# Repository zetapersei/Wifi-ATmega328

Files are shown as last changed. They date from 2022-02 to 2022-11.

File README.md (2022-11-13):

# Wifi-ATmega328
### Simple board with esp8266 + ATMega328

##### The board hardware include one esp8266, one AtMega328P together power unit 12-5 vcc -> 3.3V.
##### A Kicad project are available in the hardware folder.
##### Atmega 328 will be programmed by ICSP connector.
#### Software:
> ##### can be used the AT firmware  (loaded in the esp8266) and the [WiFiEspAT library](https://github.com/jandrassy/WiFiEspAT.git)
> ##### try to use with the [WiFiESPNow library](https://github.com/yoursunny/WifiEspNow) running in the esp8266 and manage with the ATMega328
#### Board Top view: 
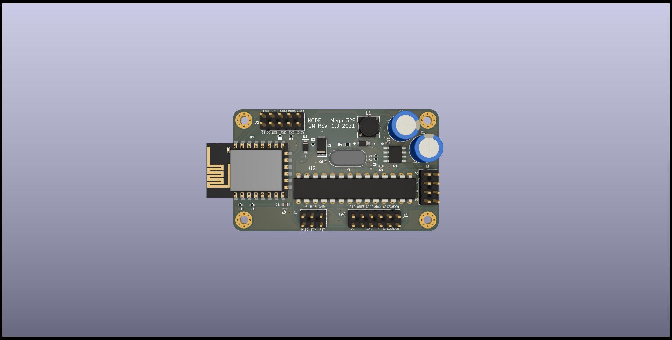
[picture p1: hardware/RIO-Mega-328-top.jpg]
top board


#### Board iso view:
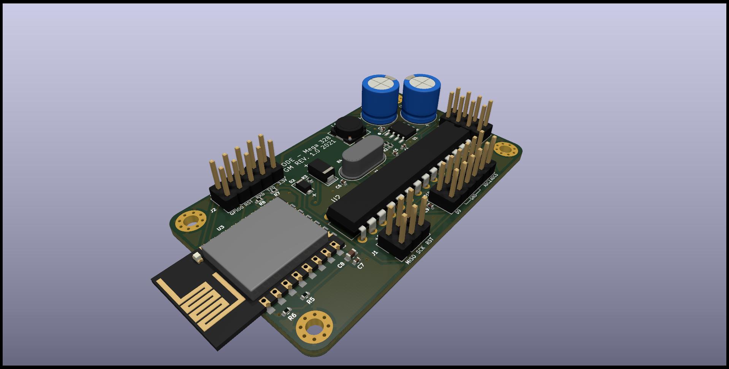
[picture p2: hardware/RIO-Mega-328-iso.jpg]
iso board


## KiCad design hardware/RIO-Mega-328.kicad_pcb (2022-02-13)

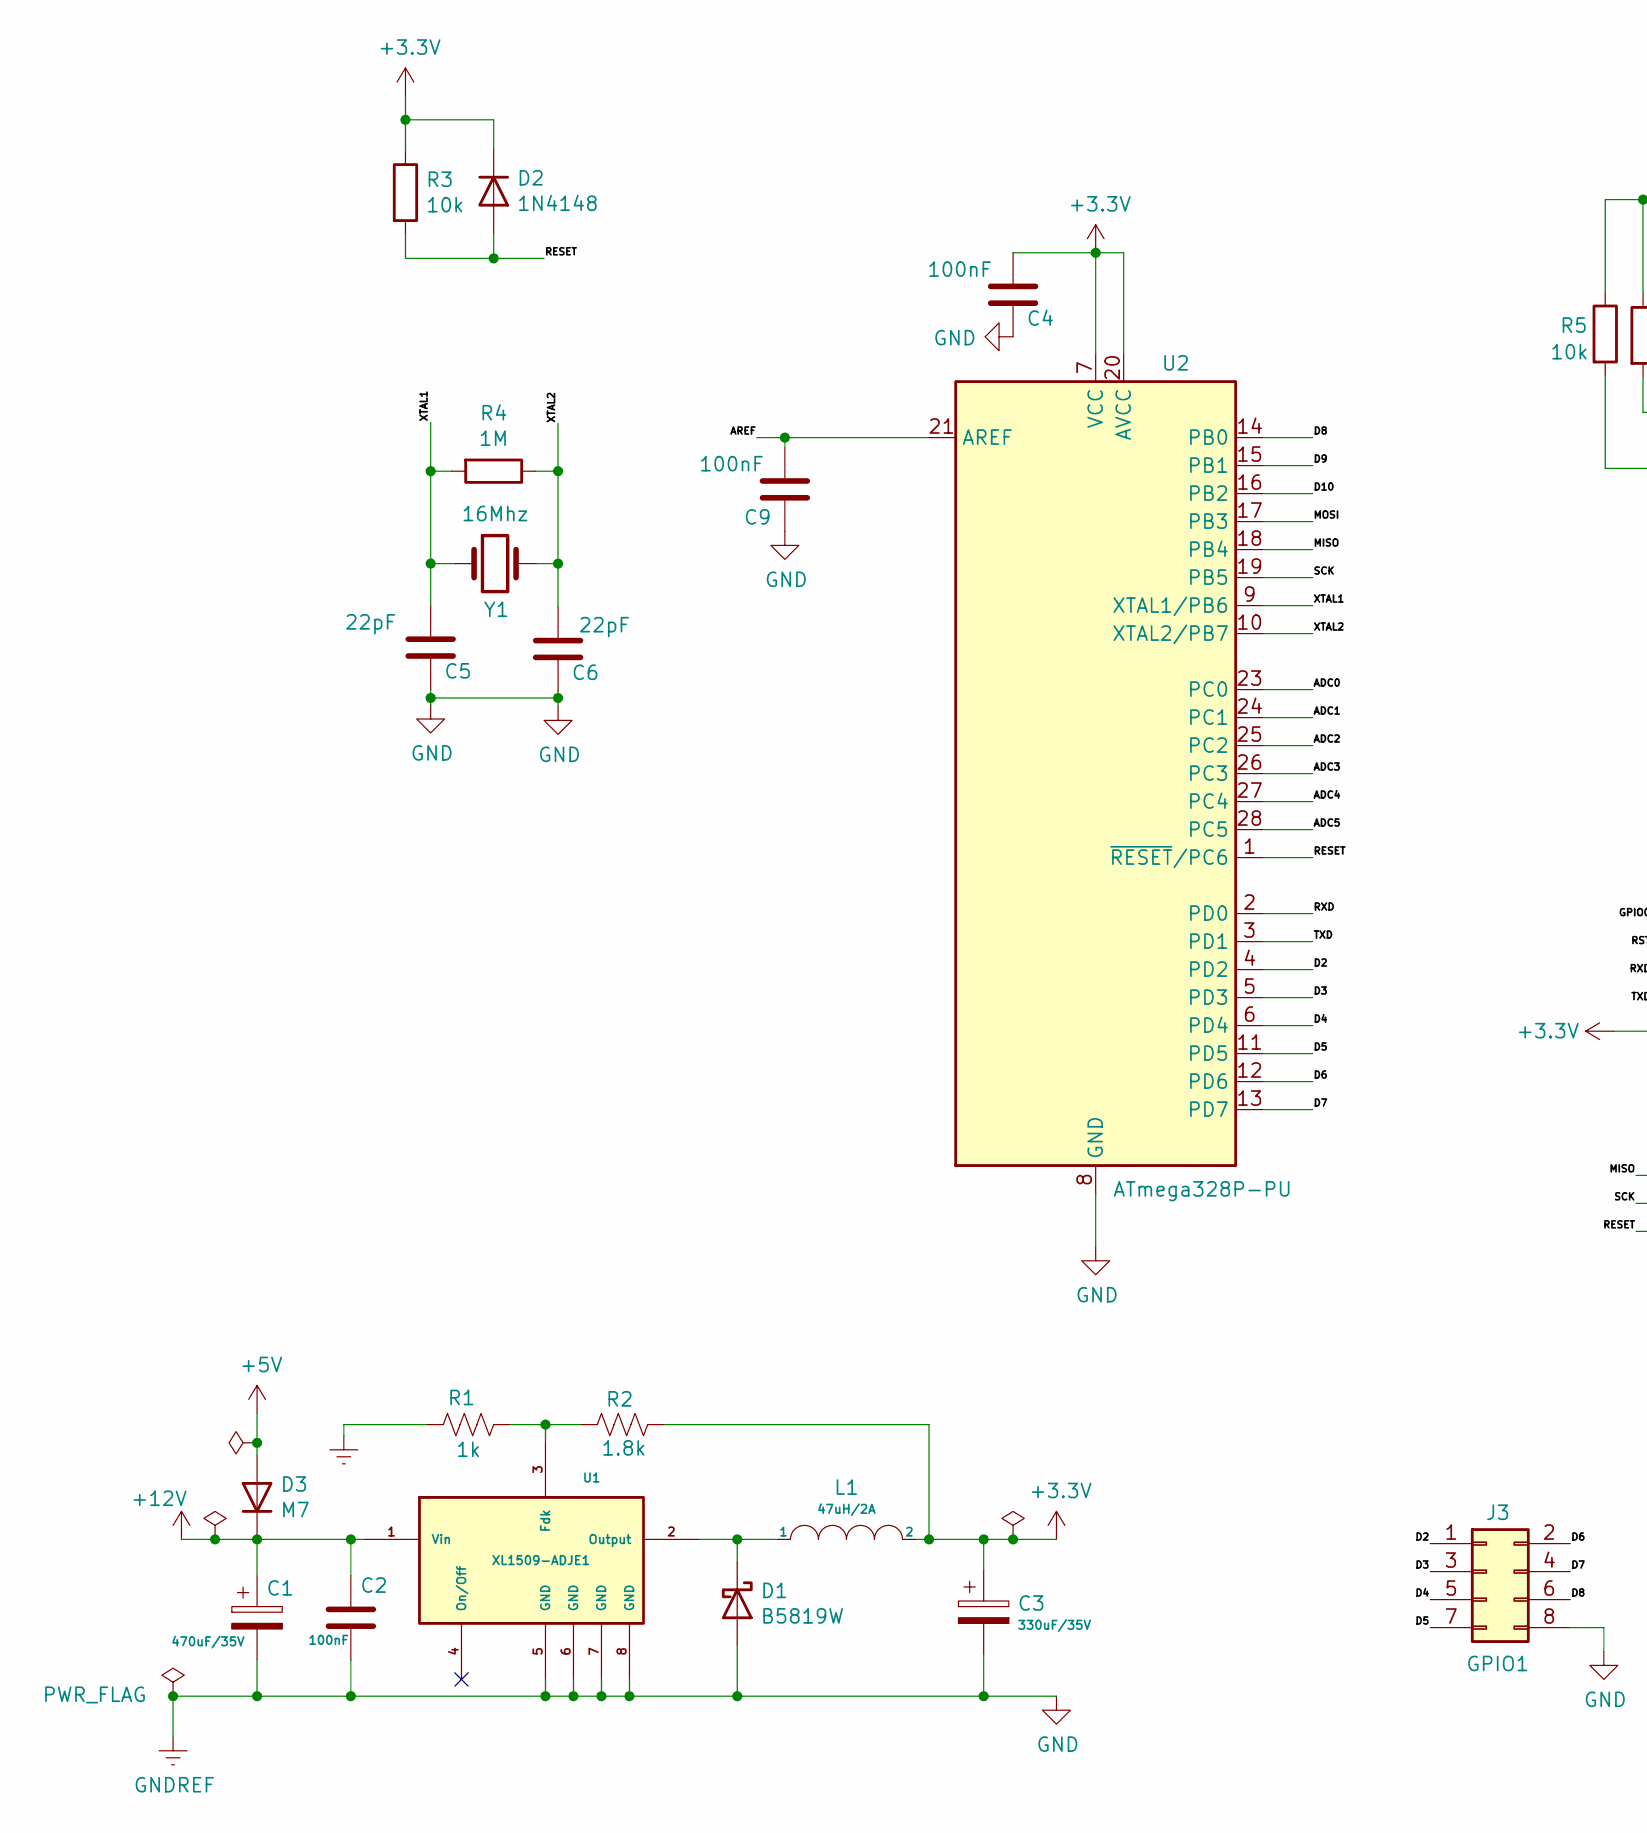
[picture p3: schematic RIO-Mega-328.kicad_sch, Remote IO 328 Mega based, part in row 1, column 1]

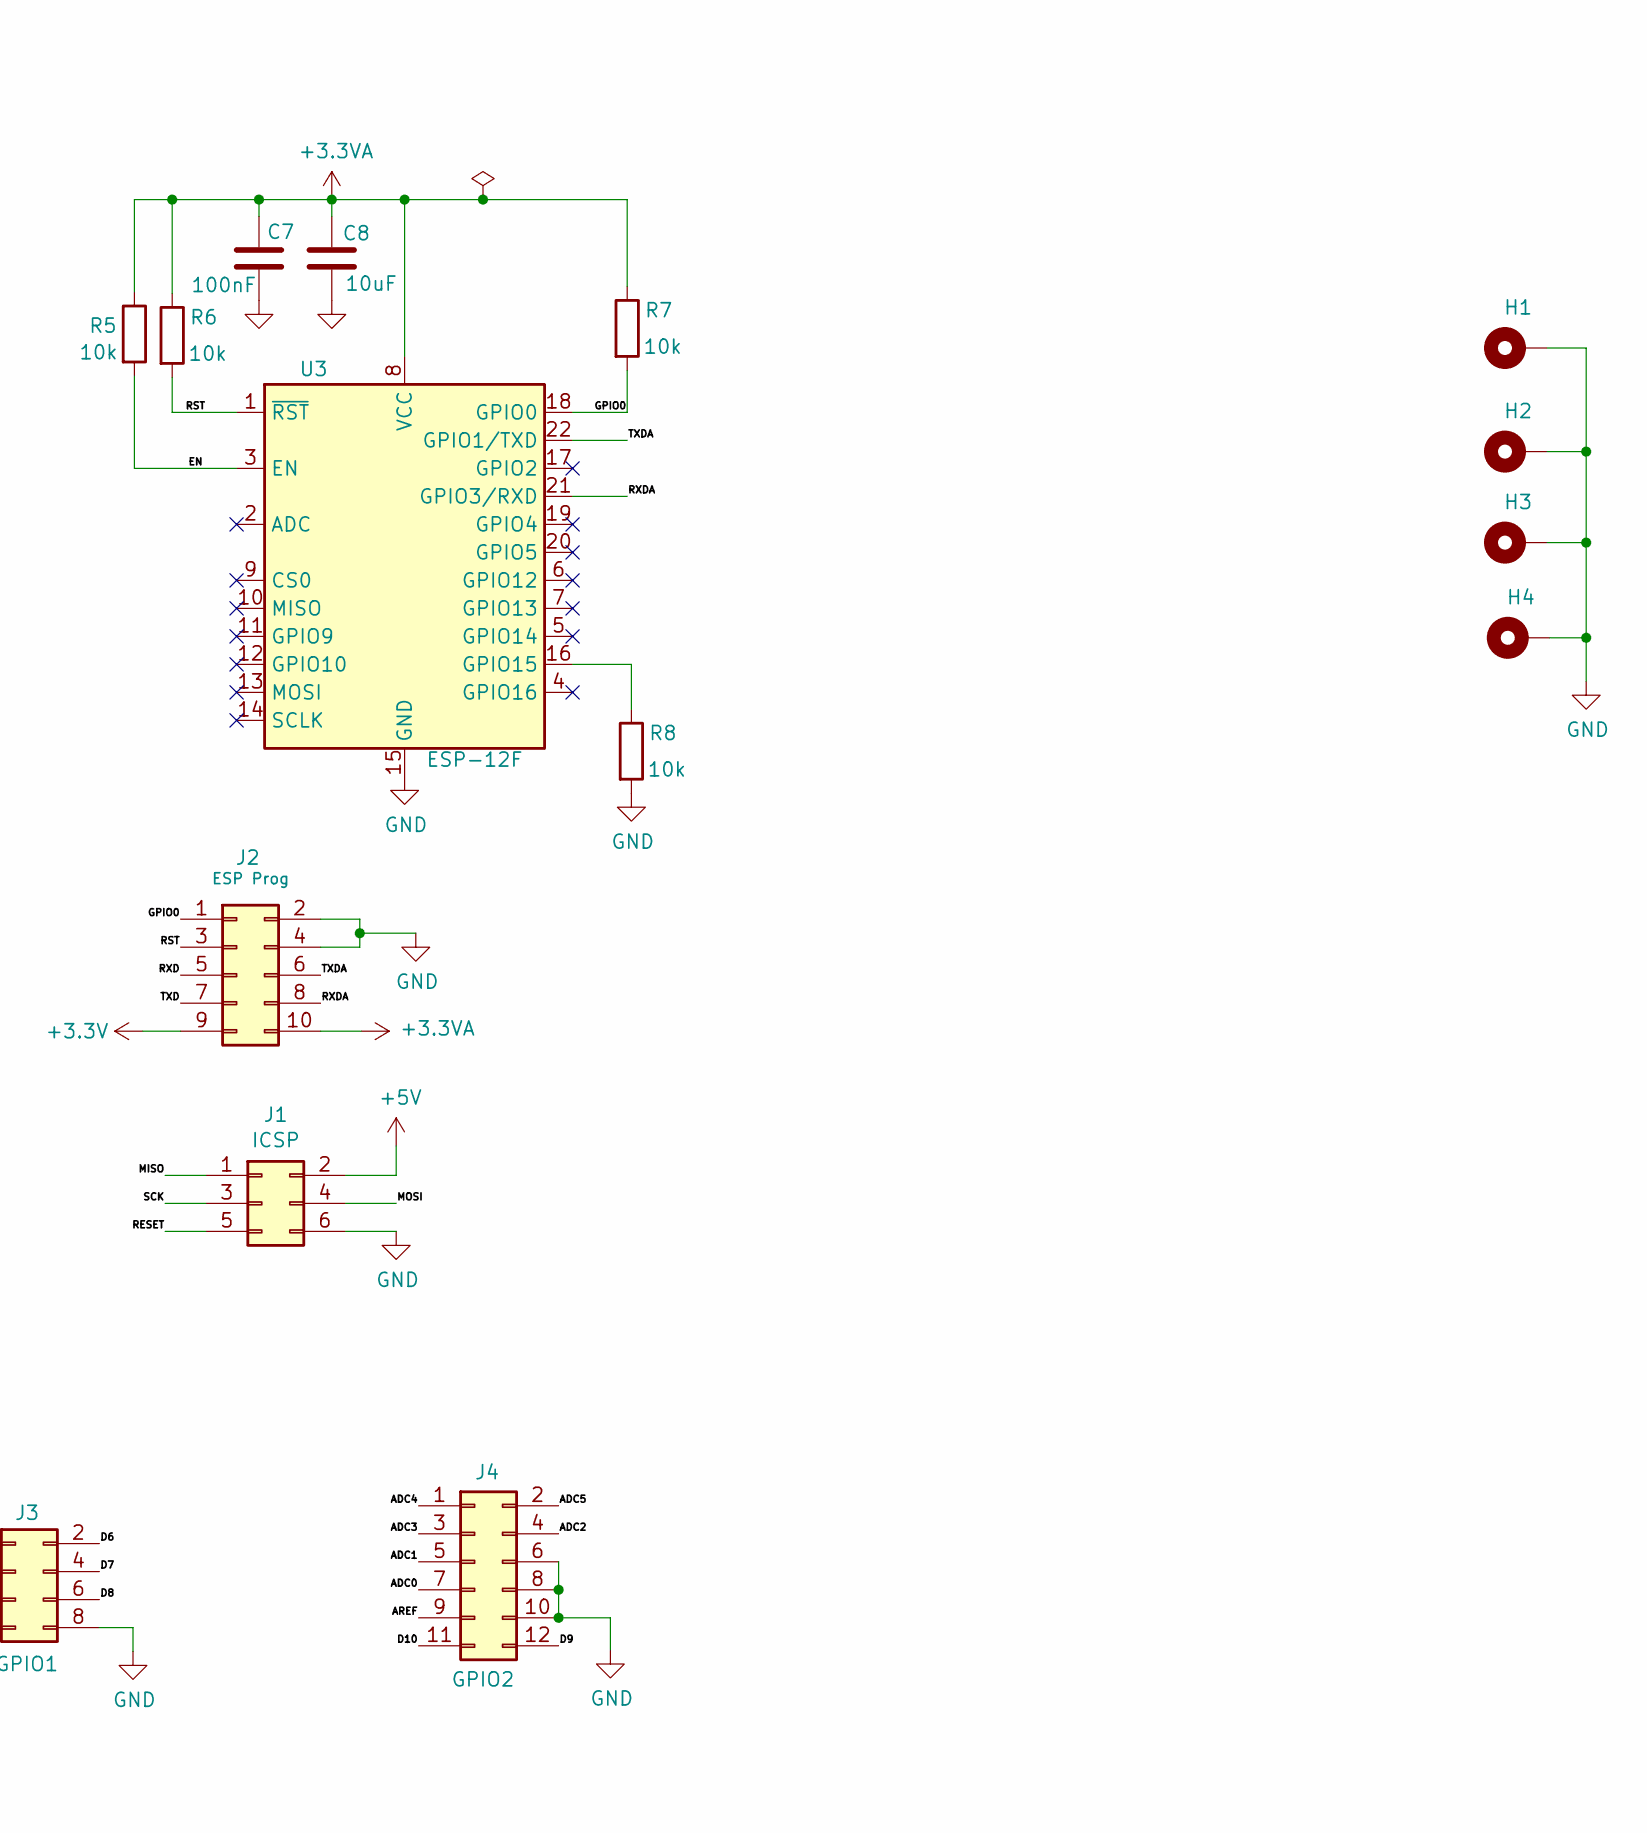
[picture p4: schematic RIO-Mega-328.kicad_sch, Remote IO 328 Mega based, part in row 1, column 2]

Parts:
C1: 470uF/35V; CP_Radial_D8.0mm_P5.00mm
C2, C4, C7, C9: 100nF; C_0402_1005Metric; LCSC C1525
C3: 330uF/35V; CP_Radial_D8.0mm_P5.00mm
C5, C6: 22pF; C_0402_1005Metric; LCSC C1555
C8: 10uF; C_0603_1608Metric; LCSC C19702
D1: B5819W; D_SOD-123F; LCSC C8598
D2: 1N4148; D_SOD-123F; LCSC C81598
D3: M7; D_SOD-128; LCSC C95872
H1, H2, H3, H4: MountingHole_Pad; MountingHole_2.5mm_Pad_Via
J1: ICSP; PinHeader_2x03_P2.54mm_Vertical
J2: ESP Prog; PinHeader_2x05_P2.54mm_Vertical
J3: GPIO1; PinHeader_2x04_P2.54mm_Vertical
J4: GPIO2; PinHeader_2x06_P2.54mm_Vertical
L1: 47uH/2A; L_6.0x6.0x4.5-SWPA-Sunlord; LCSC C36414
R1: 1k; R_0402_1005Metric; LCSC C11702
R2: 1.8k; R_0402_1005Metric; LCSC C4177
R3: 10k; R_0402_1005Metric; LCSC C25774
R4: 1M; R_0603_1608Metric; LCSC C22935
R5, R6, R7, R8: 10k; R_0402_1005Metric; LCSC C25744
U1: XL1509-ADJE1; SOP-8_3.9x4.9mm_P1.27mm; LCSC C74192
U2: ATmega328P-PU; DIP-28_W7.62mm
U3: ESP-12F; ESP-12E; LCSC C82891
Y1: 16Mhz; Crystal_HC18-U_Vertical

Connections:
+3.3VA: C7.1, C8.1, J2.10, R5.1, R6.1, R7.1, U3.8 (VCC)
+3V3: C3.1, C4.1, D2.1 (K), J2.9, L1.2, R2.1, R3.1, U2.7 (VCC), U2.20 (AVCC)
+5V: D3.2 (A), J1.2
+12V: C1.1, C2.1, D3.1 (K), U1.1 (Vin)
/ADC0: J4.7, U2.23 (PC0)
/ADC1: J4.5, U2.24 (PC1)
/ADC2: J4.4, U2.25 (PC2)
/ADC3: J4.3, U2.26 (PC3)
/ADC4: J4.1, U2.27 (PC4)
/ADC5: J4.2, U2.28 (PC5)
/AREF: C9.1, J4.9, U2.21 (AREF)
/D2: J3.1, U2.4 (PD2)
/D3: J3.3, U2.5 (PD3)
/D4: J3.5, U2.6 (PD4)
/D5: J3.7, U2.11 (PD5)
/D6: J3.2, U2.12 (PD6)
/D7: J3.4, U2.13 (PD7)
/D8: J3.6, U2.14 (PB0)
/D9: J4.12, U2.15 (PB1)
/D10: J4.11, U2.16 (PB2)
/EN: R5.2, U3.3 (EN)
/GPIO0: J2.1, R7.2, U3.18 (GPIO0)
/MISO: J1.1, U2.18 (PB4)
/MOSI: J1.4, U2.17 (PB3)
/RESET: D2.2 (A), J1.5, R3.2, U2.1 (~RESET/PC6)
/RST: J2.3, R6.2, U3.1 (~RST)
/RXD: J2.5, U2.2 (PD0)
/RXDA: J2.8, U3.21 (GPIO3/RXD)
/SCK: J1.3, U2.19 (PB5)
/TXD: J2.7, U2.3 (PD1)
/TXDA: J2.6, U3.22 (GPIO1/TXD)
/XTAL1: C5.1, R4.2, U2.9 (XTAL1/PB6), Y1.1
/XTAL2: C6.1, R4.1, U2.10 (XTAL2/PB7), Y1.2
GND: C1.2, C2.2, C3.2, C4.2, C5.2, C6.2, C7.2, C8.2, C9.2, D1.2 (A), H1.1, H2.1, H3.1, H4.1, J1.6, J2.2, J2.4, J3.8, J4.6, J4.8, J4.10, R1.2, R8.2, U1.5 (GND), U1.6 (GND), U1.7 (GND), U1.8 (GND), U2.8 (GND), U2.22 (GND), U3.15 (GND)
unnamed: D1.1 (K), L1.1, U1.2 (Output)
unnamed: R1.1, R2.2, U1.3 (Fdk)
unnamed: R8.1, U3.16 (GPIO15)

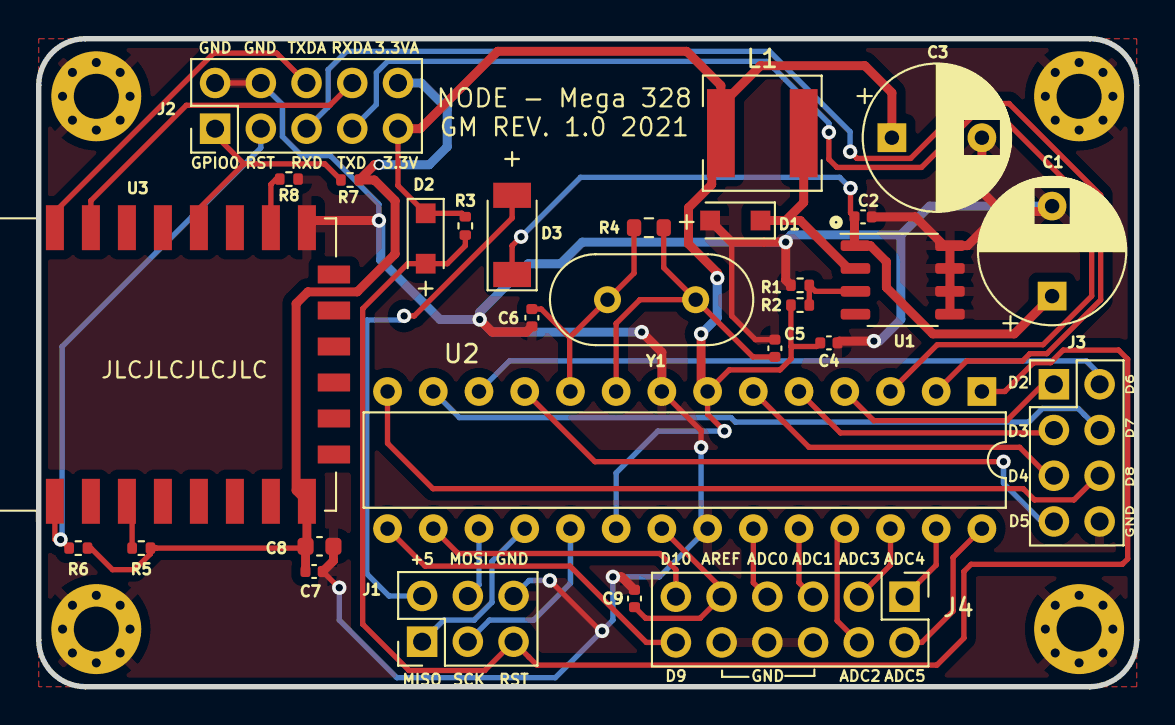
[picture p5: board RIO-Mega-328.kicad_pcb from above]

Board: 2 copper layers, 61.0 x 36.0 mm, 33 parts (0 on the bottom side), 37 nets.
